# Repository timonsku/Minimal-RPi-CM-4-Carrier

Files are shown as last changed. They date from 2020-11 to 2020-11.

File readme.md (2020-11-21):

Some photos can be found here: https://hackaday.io/project/175832-minimal-raspberry-pi-cm-4-carrier

Why
------
The goal was to show how little you have to do to do a fairly feature rich carrier board for the Compute Module 4. Also to demonstrate that you don't have to be scared by high-speed signals like HDMI and that they can still work fine in very bad conditions like a single layer PCB like this one without a reference plane underneath.

Please only use this as a starting point if at all and take a look at the open reference design by the Pi foundation for a more in-depth carrier design. This design skips several saftey features like load switches on the USB and HDMI, most of the time that's fine but you should make sure that you really don't care about that.

Please do not see this as best pracitize what so ever when it comes to routing. This PCB was made for milling a CNC and thus a lot of very bad trade offs were made that you can completely avoid by using a normal PCB fab.

Also do please attempt to do some impedance matching. An online calculator to get the correct trace width is already an ok approximation for most hobby use cases. JLC f.e. has their own calculator tuned to their specific stackups: https://cart.jlcpcb.com/impedanceCalculation

4 Layer PCBs are to be had for 5$ and less now a days so I really suggest using 4 layers, no matter what you plan.

The PCB is done in Eagle, if you use KiCad I suggest just using the schematic as a starting point and use the official Dev Board carrier design as your basis as that already comes as a KiCad design.

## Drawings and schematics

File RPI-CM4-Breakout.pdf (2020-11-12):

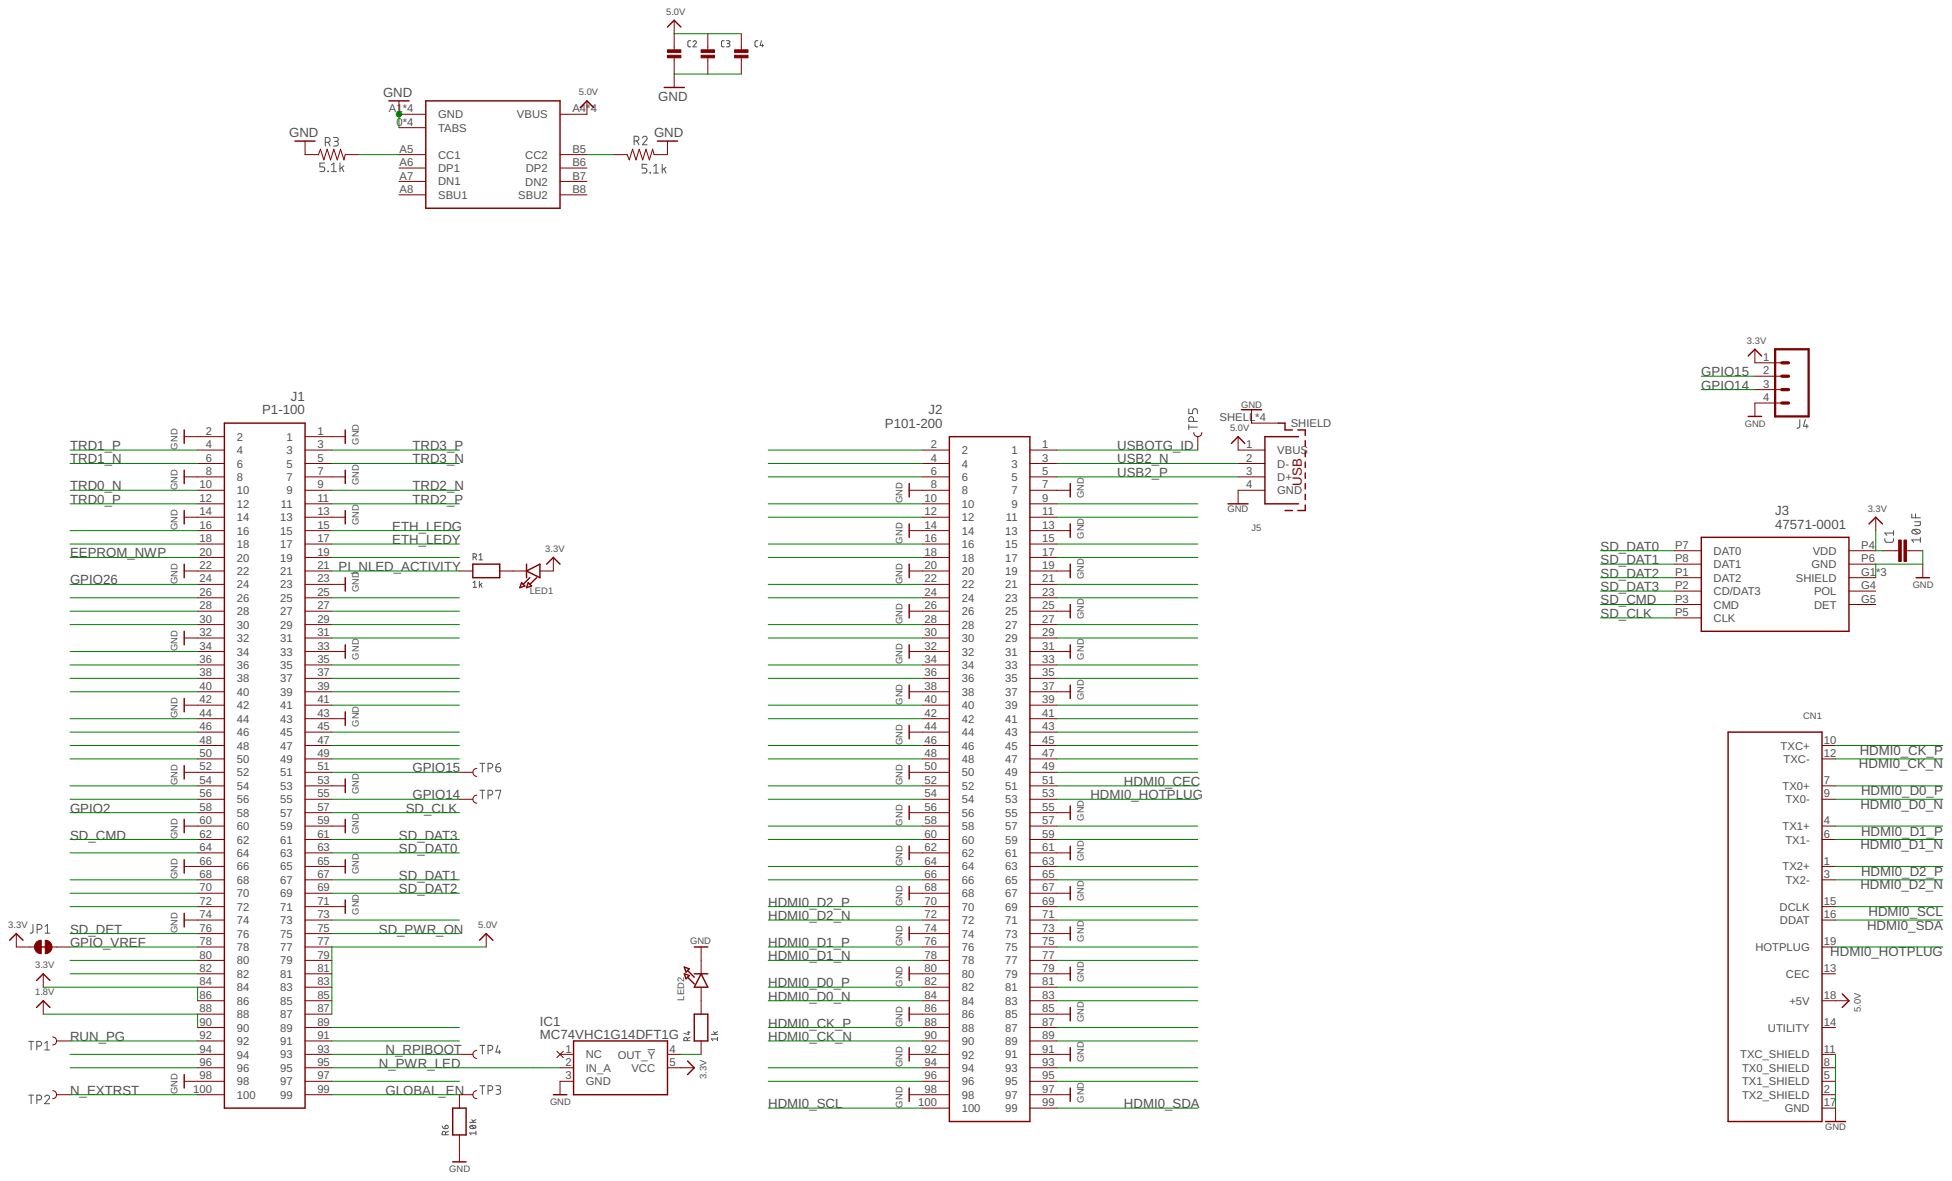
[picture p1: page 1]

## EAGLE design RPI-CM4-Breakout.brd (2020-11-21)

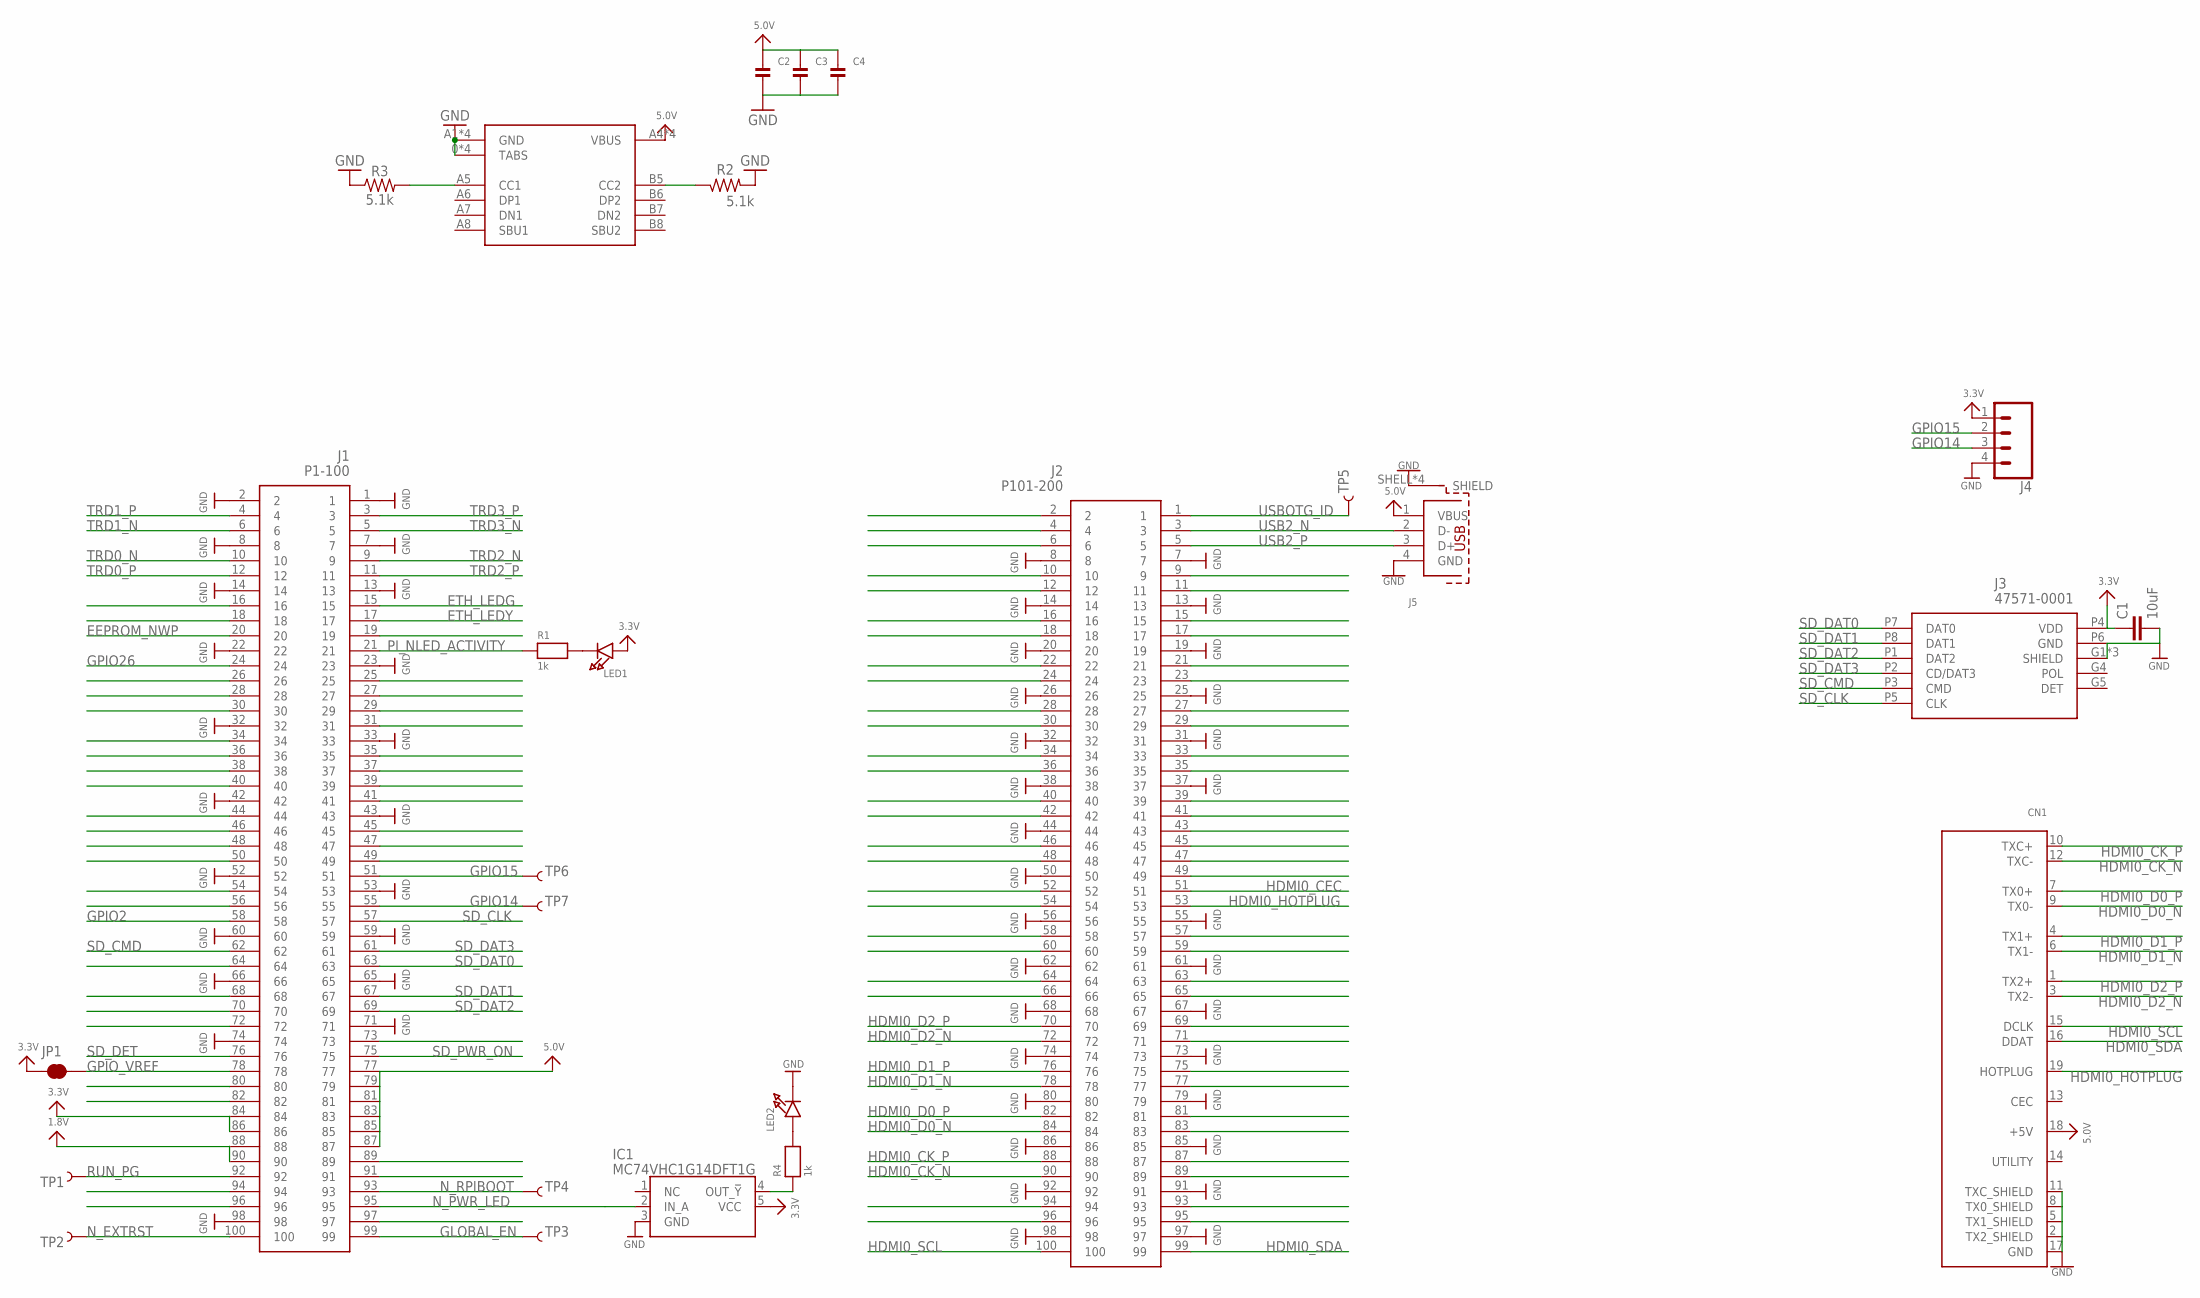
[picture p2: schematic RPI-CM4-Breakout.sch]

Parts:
C1: 10uF; 0603
C2, C3, C4: CAP_CERAMIC0402; 0402
CN1: HDMI_MOLEX_47151-0001
IC1: MC74VHC1G14DFT1G; SOT65P210X110-5N
J1: P1-100; DF40C100DS04V51
J2: P101-200; DF40C100DS04V51
J3: 47571-0001
J4: CONN_04SMD_RA_FEMALE; 1X04_SMD_RA_FEMALE
J5: 629104190121
JP1: JUMPER-SMT_2_NC_TRACE_NO-SILK; SMT-JUMPER_2_NC_TRACE_NO-SILK
LED1, LED2: LED0603; CHIPLED_0603
R1, R4: 1k; _0402MP
R2, R3: 5.1k; 0603
TP1, TP2, TP3, TP4, TP5, TP6, TP7: TEST-POINT3X5; PAD.03X.05
U$59: TYPE-C-31-M-12; USB-TYPE-C_16PIN-MALE-TYPE-C-31-M-12

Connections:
1.8V: J1.88, J1.90
3.3V: C1.1, IC1.5 (VCC), J1.84, J1.86, J3.P4 (VDD), J4.1, JP1.1, LED1.A
5.0V: C2.1, C3.1, C4.1, CN1.18 (+5V), J1.77, J1.79, J1.81, J1.83, J1.85, J1.87, J5.1 (VBUS), U$59.A4 (VBUS), U$59.A9 (VBUS), U$59.B4 (VBUS), U$59.B9 (VBUS)
A0/CC2: R3.2, U$59.A5 (CC1)
A3/CC1: R2.1, U$59.B5 (CC2)
EEPROM_NWP: J1.20
ETH_LEDG: J1.15
ETH_LEDY: J1.17
GLOBAL_EN: J1.99, TP3.P$1
GND: C1.2, C2.2, C3.2, C4.2, CN1.2 (TX2_SHIELD), CN1.5 (TX1_SHIELD), CN1.8 (TX0_SHIELD), CN1.11 (TXC_SHIELD), CN1.17 (GND), CN1.P$1 (GND), CN1.P$2 (GND), CN1.P$3 (GND), CN1.P$4 (GND), IC1.3 (GND), J1.1, J1.2, J1.7, J1.8, J1.13, J1.14, J1.22, J1.23, J1.32, J1.33, J1.42, J1.43, J1.52, J1.53, J1.59, J1.60, J1.65, J1.66, J1.71, J1.74, J1.98, J2.7, J2.8, J2.13, J2.14, J2.19, J2.20, J2.25, J2.26, J2.31, J2.32, J2.37, J2.38, J2.44, J2.50, J2.55, J2.56, J2.61, J2.62, J2.67, J2.68, J2.73, J2.74, J2.79, J2.80, J2.85, J2.86, J2.91, J2.92, J2.97, J2.98, J3.G1 (SHIELD), J3.G2 (SHIELD), J3.G3 (SHIELD), J3.P6 (GND), J4.4, J5.4 (GND), J5.SHELL (SHIELD), J5.SHELL1 (SHIELD), J5.SHELL2 (SHIELD), J5.SHELL3 (SHIELD), LED2.C, R2.2, R3.1, U$59.0 (TABS), U$59.0-1 (TABS), U$59.0-2 (TABS), U$59.0-3 (TABS), U$59.A1 (GND), U$59.A12 (GND), U$59.B1 (GND), U$59.B12 (GND)
GPIO2: J1.58
GPIO14: J1.55, J4.3, TP7.P$1
GPIO15: J1.51, J4.2, TP6.P$1
GPIO26: J1.24
GPIO_VREF: J1.78, JP1.2
HDMI0_CEC: J2.51
HDMI0_CK_N: CN1.12 (TXC-), J2.90
HDMI0_CK_P: CN1.10 (TXC+), J2.88
HDMI0_D0_N: CN1.9 (TX0-), J2.84
HDMI0_D0_P: CN1.7 (TX0+), J2.82
HDMI0_D1_N: CN1.6 (TX1-), J2.78
HDMI0_D1_P: CN1.4 (TX1+), J2.76
HDMI0_D2_N: CN1.3 (TX2-), J2.72
HDMI0_D2_P: CN1.1 (TX2+), J2.70
HDMI0_HOTPLUG: CN1.19 (HOTPLUG), J2.53
HDMI0_SCL: CN1.15 (DCLK), J2.100
HDMI0_SDA: CN1.16 (DDAT), J2.99
unnamed: LED1.C, R1.2
unnamed: IC1.4 (OUT_!Y), R4.1
unnamed: LED2.A, R4.2
N_EXTRST: J1.100, TP2.P$1
N_PWR_LED: IC1.2 (IN_A), J1.95
N_RPIBOOT: J1.93, TP4.P$1
PI_NLED_ACTIVITY: J1.21, R1.1
RUN_PG: J1.92, TP1.P$1
SD_CLK: J1.57, J3.P5 (CLK)
SD_CMD: J1.62, J3.P3 (CMD)
SD_DAT0: J1.63, J3.P7 (DAT0)
SD_DAT1: J1.67, J3.P8 (DAT1)
SD_DAT2: J1.69, J3.P1 (DAT2)
SD_DAT3: J1.61, J3.P2 (CD/DAT3)
SD_DET: J1.76
SD_PWR_ON: J1.75
TRD0_N: J1.10
TRD0_P: J1.12
TRD1_N: J1.6
TRD1_P: J1.4
TRD2_N: J1.9
TRD2_P: J1.11
TRD3_N: J1.5
TRD3_P: J1.3
USB2_N: J2.3, J5.2 (D-)
USB2_P: J2.5, J5.3 (D+)
USBOTG_ID: J2.1, TP5.P$1

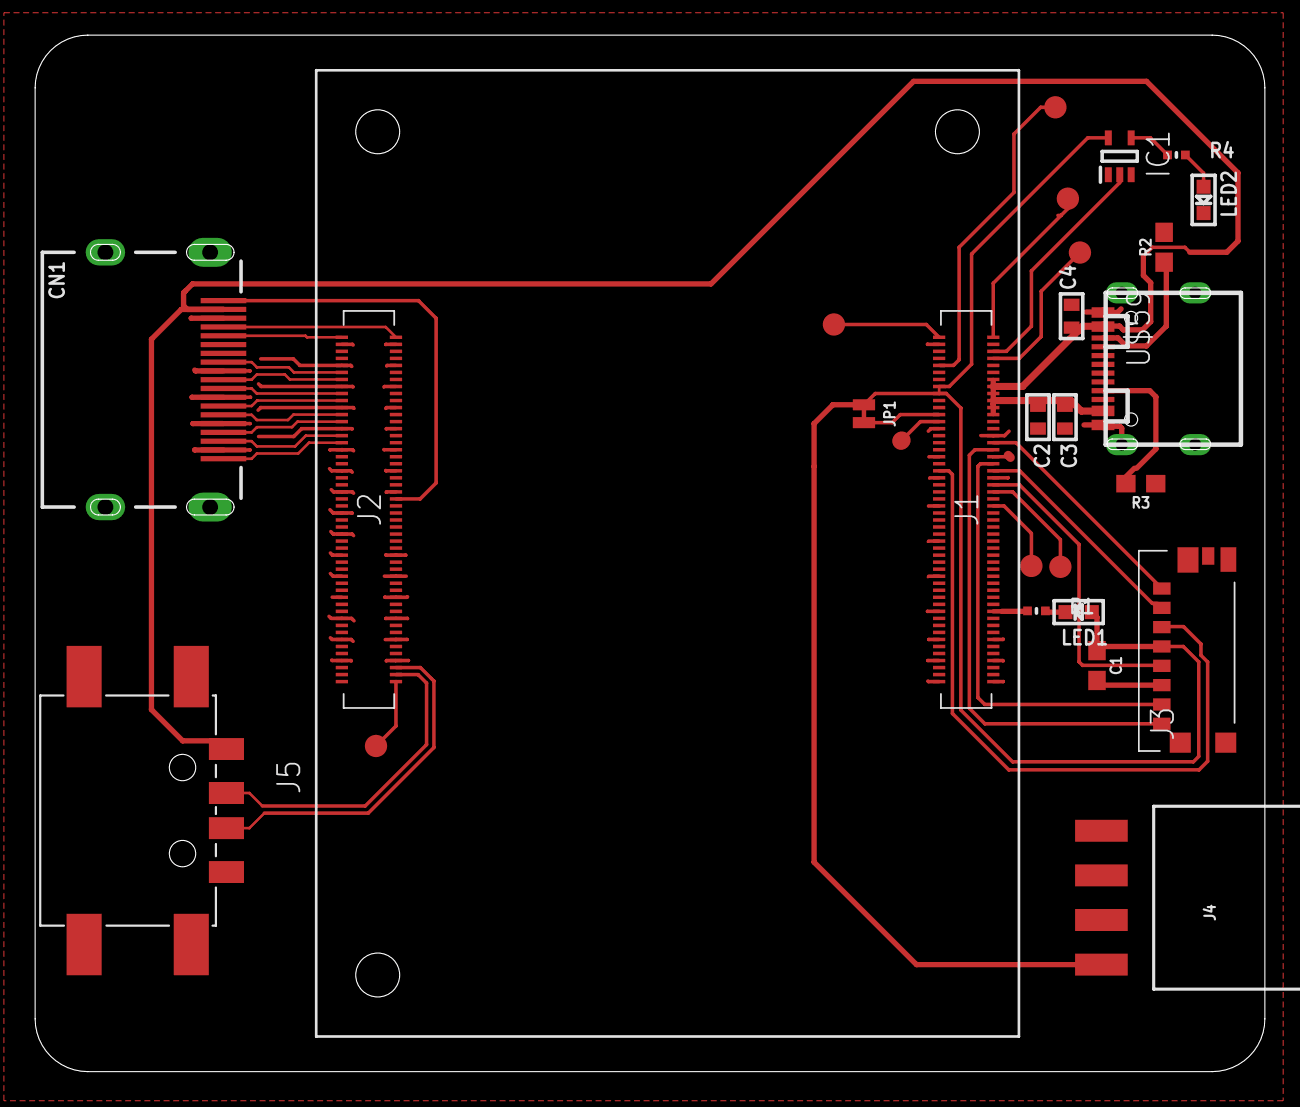
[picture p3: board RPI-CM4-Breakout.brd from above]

Board: 2 copper layers, 70.0 x 59.0 mm, 26 parts (0 on the bottom side), 38 nets.

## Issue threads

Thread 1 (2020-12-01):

Ethernet port

adminy, 2020-12-01:
I think it's really amazing how minimal this is! However, isn't an ethernet port more useful than usb and hdmi & sd combined?

with an ethernet port, you have network boot, ssh which is more useful than having a screen, especially on a raspberry pi. Also any resource can be downloaded and stored in ram.

So waiting for the simplest yet design which will be just a single ethernet port that delivers everything else

PTS93, 2020-12-01:
This is just a data dump for a quick and dirty demonstration. I might make another more properly made educational board later on that will integrate Ethernet but this board here will see no changes.

Closed 2020-12-01.

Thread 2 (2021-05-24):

Compute module  connector

Sampozzo, 2021-05-24:
Hi, thank you for sharing this!
I'm buying a first rpi cm4 to start learning on it, but i can't understand the connector that need to be used.
I cant find any info on it or websites selling them. Maybe i simple dont9knie how to search. Can you please give me an idea on where i can buy it in europe?

Thank you very much.

Sampozzo, 2021-05-25:
I've found this: https://it.farnell.com/hirose-hrs/df40c-100dp-0-4v-51/conn-stacking-header-100pos-2row/dp/2427678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

Any one can confirm it is the right connector?

timonsku, 2021-05-25:
The part number is in the datasheet. It is DF40C-100DS-0.4v usually listed as DF40C-100DS-0.4V(51)
Mouser still has some stock. The one you linked my be compatible but better to check the datasheet if that is the case.

Sampozzo, 2021-05-25:
Thank you very much!

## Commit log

2020-11-12 Initial single layer version
    [RPI-CM4-Breakout.brd, RPI-CM4-Breakout.sch]
2020-11-21 Removed misleading pull-down on GLOBAL_EN
    [RPI-CM4-Breakout.brd, RPI-CM4-Breakout.sch]

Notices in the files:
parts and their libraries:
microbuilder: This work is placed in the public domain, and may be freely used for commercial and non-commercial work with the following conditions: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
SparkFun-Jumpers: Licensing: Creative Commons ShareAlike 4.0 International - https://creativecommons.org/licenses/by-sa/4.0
